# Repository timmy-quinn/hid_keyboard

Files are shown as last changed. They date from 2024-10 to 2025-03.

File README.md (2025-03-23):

# The KeyBird
The KeyBird is a BLE split keyboard with a vertical stagger and 5 thumb keys. It features hot-swap sockets compatible with any MX switches. The design is inspired by other popular split keyboards such as the [Corne](https://github.com/foostan/crkbd) or [Kinesis keyboards](https://kinesis-ergo.com/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).
  
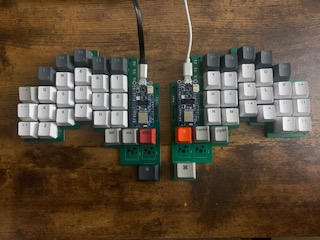
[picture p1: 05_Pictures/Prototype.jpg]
  

## Project Status
### Firmware 
- [x] Proof of concept: Single board BLE HID over GATT
- [x] Key matrix
- [x] Multi-role functionality
- [x] Process keypresses from secondary keyboard
- [ ] Improvements based on user experience
### Electronics 
- [x] Proof of concept: Perf board
- [x] Design and order PCBs
- [x] Assemble PCBs
- [ ] Improvements based on user experience 
### Case
- [x] Design case and plate
- [ ] 3D-print case and plate
- [ ] Build a wooden case
### Stretch goals
- [ ] Enable tenting
- [ ] Add NFC pairing capability
- [ ] Add USB option
- [ ] Add RGB LEDs
- [ ] OTA update
- [ ] Keyboard configuration via file upload

### Design Notes (AKA why does it look like that?) 
If you've never plunged down the ergonomic keyboard rabbit hole before, I'll give you a quick breakdown explaining some of the design decisions that went into my keyboard.  
  
**1. Split**  
Splitting a keyboard in half allows your hands and wrists to rest at a more natural and comfortable position  
**2. Ortholinear**   
This is just a fancy way to say that the keys are layed out in vertical columns, unlike typical keyboards, where the keys form horizontal rows, but are vertically staggered. Using vertical columns, especially when those columns are staggered to conform with the length of each finger, provides a more ergnomic typing experience.
**3. Reduced key count**  
Reducing the number of keys enables you to type faster and more efficiently since you do not have to stretch your fingers for hard to reach keys. This is especially helpful for coding, where you have to use symbols like ~ and | more often than most typers. But you might wonder, if you reduce the number of keys, don't you reduct the number of characters you can type? That is where the next design principle comes into play.
**4. Layers**  
A reduced keyboard makes up for its lack of keys by using layers. Layers are changed with the press of a button. When pressing the layer button, the same physical keys will transmit a different character to your PC. The shift key on a normal keyboard functions like this. On a reduced size keyboard, there will be at least one other layer key besides the shift key, enabling the same number of characters to be typed with fewer keys.  
**5. Thumb cluster**  
The thumb cluster solves one of the inefficiences of a standard keyboard, where both of your thumbs are dedicated to a single key. Adding a thumb cluster enables you to press far more keys without increasing how much you have to move your hand. This helps counter balance the reduced key size, while still preventing you from have to stretch and reach to use necessary keys.  
  
## Development requirements  
For hardware development KiCad 8 is used. 

For firmware Development nRF Connect SDK v2.6.1 is required. It can be conveniently used with the NRF Visual Studio Code Extension. More information can be found [here](https://docs.nordicsemi.com/bundle/ncs-latest/page/nrf/installation/install_ncs.html). 

#### Generating first build.  
1. Navigate to the NRF Connect Tab in VS Code.  
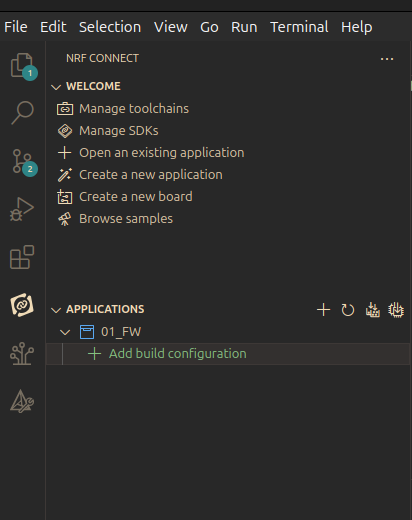
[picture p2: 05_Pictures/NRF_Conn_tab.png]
  
  
2. Select Add Build Configuration.  
  
  
3. Choose one of the presets. The presets are determined by the CMakePresets.json, but they can be simply be selected in the GUI.    
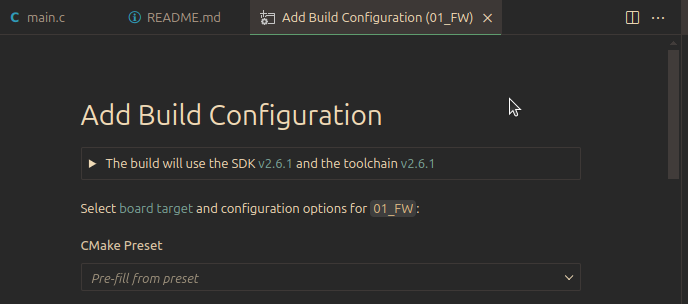
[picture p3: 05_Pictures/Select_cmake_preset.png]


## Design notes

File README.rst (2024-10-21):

.. _peripheral_hids_keyboard:

Bluetooth: Peripheral HIDS keyboard
###################################

.. contents::
   :local:
   :depth: 2

The Peripheral HIDS keyboard sample demonstrates how to use the :ref:`hids_readme` to implement a keyboard input device that you can connect to your computer.

The sample also shows how to perform LE Secure Connections Out-of-Band pairing using NFC.

Requirements
************

The sample supports the following development kits:

.. table-from-sample-yaml::

.. include:: /includes/tfm.txt

.. include:: /includes/hci_ipc_overlay.txt

If the NFC_OOB_PAIRING feature is enabled, the sample requires a smartphone or a tablet with Android v8.0.0 or newer.
- 

Overview
********

The sample uses the buttons on a development kit to simulate keys on a keyboard.
One button simulates the letter keys by generating letter keystrokes for a predefined string.
A second button simulates the Shift button and shows how to modify the letter keystrokes.
An LED displays the Caps Lock state, which can be modified by another connected keyboard.

This sample exposes the HID GATT Service.
It uses a report map for a generic keyboard.

LE Secure Out-of-Band pairing with NFC is enabled by default in this sample.
You can disable this feature by clearing the `NFC_OOB_PAIRING` flag in the application configuration.
The following paragraphs describe the application behavior when NFC pairing is enabled.

When the application starts, it initializes and starts the NFCT peripheral that is used for pairing.
The application does not start advertising immediately, but only when the NFC tag is read by an NFC polling device, for example a smartphone or a tablet with NFC support.
To trigger advertising without NFC, press **Button 4**.
The NDEF message that the tag sends to the NFC device contains data required to initiate pairing.
To start the NFC data transfer, the NFC device must touch the NFC antenna that is connected to the nRF52 device.

After reading the tag, the device can pair with the nRF52 device which is advertising.
After connecting, the sample application behaves in the same way as the original HID Keyboard sample.
Reading the NFC tag again when the application is in a connected state causes disconnection.
When the connection is lost, advertising does not restart automatically.

User interface
**************

Button 1:
   Sends one character of the predefined input ("hello\\n") to the computer.

   When pairing, press this button to confirm the passkey value that is printed on the COM listener to pair with the other device.

Button 2:
   Simulates the Shift key.

   When pairing, press this button to reject the passkey value which is printed on the COM listener to prevent pairing with the other device.

LED 1:
   Blinks with a period of two seconds with the duty cycle set to 50% when the main loop is running and the device is advertising.

LED 2:
   Lit when at least one device is connected.

LED 3:
   Indicates if Caps Lock is enabled.

If the `NFC_OOB_PAIRING` feature is enabled:

Button 4:
   Starts advertising.

LED 4:
   Indicates if an NFC field is present.

Configuration
*************

|config|

Setup
=====

The HID service specification does not require encryption (:kconfig:option:`CONFIG_BT_HIDS_DEFAULT_PERM_RW_ENCRYPT`), but some systems disconnect from the HID devices that do not support security.

Building and running
********************
.. |sample path| replace:: :file:`samples/bluetooth/peripheral_hids_keyboard`

.. include:: /includes/build_and_run_ns.txt

Testing
=======

After programming the sample to your development kit, you can test it either by connecting the kit as keyboard device to a Microsoft Windows computer or by connecting to it with `nRF Connect for Desktop`_.

Testing with a Microsoft Windows computer
-----------------------------------------

To test with a Microsoft Windows computer that has a Bluetooth® radio, complete the following steps:

1. Power on your development kit.
#. Press **Button 4** on the kit if the device is not advertising.
   A blinking **LED 1** indicates that the device is advertising.
#. |connect_terminal|
#. On your Windows computer, search for Bluetooth devices and connect to the device named "NCS HIDS keyboard".
#. Observe that the connection state is indicated by **LED 2**.
#. Open a text editor (for example, Notepad).
#. Repeatedly press **Button 1** on the kit.
   Every button press sends one character of the test message "hello" (the test message includes a carriage return) to the computer, and this will be displayed in the text editor.
#. Press **Button 2** and hold it while pressing **Button 1**.
   Observe that the next letter of the "hello" message appears as capital letter.
   This is because **Button 2** simulates the Shift key.
#. Turn on Caps Lock on the computer.
   Observe that **LED 3** turns on.
   This confirms that the output report characteristic has been written successfully on the HID device.
#. Turn Caps Lock off on the computer.
   Observe that **LED 3** turns off.
#. Disconnect the computer from the device by removing the device from the computer's devices list.

Testing with nRF Connect for Desktop
------------------------------------

To test with `nRF Connect for Desktop`_, complete the following steps:

1. Power on your development kit.
#. Press **Button 4** on the kit if the device is not advertising.
   A blinking **LED 1** indicates that the device is advertising.
#. |connect_terminal|
#. Start `nRF Connect for Desktop`_.
#. Open the Bluetooth Low Energy app.
#. Connect to the device from the app. The device is advertising as "NCS HIDS keyboard".
#. Pair the devices:

   a. Click the :guilabel:`Settings` button for the device in the app.
   #. Select :guilabel:`Pair`.
   #. Optionally, select :guilabel:`Perform Bonding`.

   Optionally, check :guilabel:`Enable MITM protection` to pair with MITM protection and use a button on the device to confirm or reject the passkey value.

   Wait until the bond is established before you continue.

#. Observe that the connection state is indicated by **LED 2**.
#. Observe that the services of the connected device are shown.
#. Enable notifications for all HID characteristics.
#. Press **Button 1** on the kit.
   Observe that two notifications are received on one of the HID Report characteristics, denoting press and release for one character of the test message.

   The first notification has the value ``00000B0000000000``, the second has the value ``0000000000000000``.
   The received values correspond to press and release of character "h".
   The format used for keyboard reports is the following byte array: ``[modifier, reserved, Key1, Key2, Key3, Key4, Key5, Key6]``.

   Similarly, further press and release events will result in press and release notifications of subsequent characters of the test string.
   Therefore, pressing **Button 1** again will result in notification of press and release reports for character "e".
#. Press **Button 2** and hold it while pressing **Button 1**.
   Pressing **Button 2** changes the modifier bit to 02, which simulates pressing the Shift key on a keyboard.

   Observe that two notifications are received on one of the HID Report characteristics, denoting press and release for one character of the test message.
   The first one has the value ``02000F0000000000``, the second has the value ``0200000000000000``.
   These values correspond to press and release of character "l" with the Shift key pressed.
#. In the Bluetooth Low Energy app, select the HID Report (which has UUID ``0x2A4D`` and the properties ``Read``, ``WriteWithoutResponse``, and ``Write``).
   Enter ``02`` in the text box and click the :guilabel:`tick mark` button.
   This sets the modifier bit of the Output Report to 02, which simulates turning Caps Lock ON.

   Observe that **LED 3** is lit.
#. Select the same HID Report again.
   Enter ``00`` in the text box and click :guilabel:`Write`.
   This sets the modifier bit to 00, which simulates turning Caps Lock OFF.

   Observe that **LED 3** turns off.
#. Disconnect the device in the Bluetooth Low Energy app.
   Observe that no new notifications are received.
#. If the advertising did not start automatically, press **Button 4** to continue advertising.
#. As bond information is preserved by the Bluetooth Low Energy app, you can immediately reconnect to the device by clicking the :guilabel:`Connect` button again.

Testing with Android using NFC for pairing
------------------------------------------

To test with an Android smartphone/tablet, complete the following steps:

1. Touch the NFC antenna with the smartphone or tablet and observe that **LED 4** is lit.
#. Observe that the device is advertising, as indicated by blinking **LED 1**.
#. Confirm pairing with 'Nordic_HIDS_keyboard' in a pop-up window on the smartphone/tablet.
#. Observe that the connection state is indicated by **LED 2**.
#. Repeatedly press **Button 1** on the kit.
   Every button press sends one character of the test message "hello" to the smartphone (the test message includes a carriage return).
#. Press **Button 2** and hold it while pressing **Button 1**.
   Observe that the next letter of the "hello" message appears as a capital letter.
   This is because **Button 2** simulates the Shift key.
#. Touch the NFC antenna with the same central device again.
#. Observe that devices disconnect.

Dependencies
************

This sample uses the following |NCS| libraries:

* :ref:`hids_readme`
* :ref:`nfc_ndef` (if the `NFC_OOB_PAIRING` option is enabled)
* :ref:`nfc_ndef_le_oob` (if the `NFC_OOB_PAIRING` option is enabled)

When the `NFC_OOB_PAIRING` feature is enabled, it also uses the Type 2 Tag library from `sdk-nrfxlib`_:

* :ref:`nrfxlib:nfc_api_type2`
* :ref:`dk_buttons_and_leds_readme`

The sample uses the following Zephyr libraries:

* :file:`include/zephyr/types.h`
* :file:`include/sys/printk.h`
* :file:`include/sys/byteorder.h`
* :ref:`GPIO Interface <zephyr:api_peripherals>`
* :ref:`zephyr:settings_api`
* :ref:`zephyr:bluetooth_api`:

  * :file:`include/bluetooth/bluetooth.h`
  * :file:`include/bluetooth/hci.h`
  * :file:`include/bluetooth/conn.h`
  * :file:`include/bluetooth/uuid.h`
  * :file:`include/bluetooth/gatt.h`
  * :file:`samples/bluetooth/gatt/bas.h`

References
**********

* `HID Service Specification`_
* `HID usage tables`_
* `Bluetooth Secure Simple Pairing Using NFC`_
* `Bluetooth Core Specification`_ Volume 3 Part H Chapter 2

The sample also uses the following secure firmware component:

* :ref:`Trusted Firmware-M <ug_tfm>`

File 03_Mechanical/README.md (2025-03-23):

#Keyboard Case and Plate Notes

[Jo scotto video gasket mount ](https://www.youtube.com/watch?v=W4mXZvFGHDg&t=625s)

- uses 4mm gaskets on both top and bottom  
- There is a 3.7 mm gap between the top of the plate and case, and bottom of plate and case,
despite the fact that a 4mm gasket is being used. This allows for the gasket to squish the
 board in place. 
- There is a gap between the side of the plate and the case of 0.25mm

[Jo Scotto case and plate](https://www.youtube.com/watch?v=7azQkSu0m_U)

[anatomy of a keyboard article](https://matt3o.com/anatomy-of-a-keyboard/) 

[cherry switches developer notes](https://www.cherry.de/en-gb/gaming/developer)

def test_layers(board):
    for drawing in board.GetDrawings():
        print("got drawing")
        print(f"Found drawing fo type:{type(drawing)} on layer ID: {drawing.GetLayer()}")
### Dimensions of a keyboard plate and case 
- From the top of the plate to the top of the PCBs is 5.0mm <br>
- The PCB and plate (when using an FR-4 plate will both be 1.6mm) <br>
    - For a 3d printed plate the plate should be thicker, 3mm to 5mm
    - At the top and bottom of a key switch are the clips. Below the clips are
    two little outcroppings that clip to the underside of the plate. To enable
     space for these little outcroppings, you need to make sure this part of the
      plate is 1.5mm thick. The area of these clips and outcroppings is 6mm long 
      and less than 1mm in width. To be safe we can add an extra mm or two for 
      tolerance. An area 7mm by 1-1.5mm should be adequate. 
- The thickness of the hot swappable socket is 1.85mm <br>
- The switch cutout holes should be 14mm by 14mm squares
<br>
#### Total distances from top of plate to bottom of case: <br>
10.45mm = 5 (top of plate to pcb) + 1.6 (pcb) + 1.85mm (hot swap socket) + 3mm (tolerance) <br>

#### Threaded inserts
For the threaded inserts that I am using, the material thickness is 3.2 mm and the length is 5.0mm

#### Integrated plate  
Raise the edged of the "case" 6mm above the "plate"

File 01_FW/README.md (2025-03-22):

# KeyBird Firmware

### Debug Tips

#### Unable to flash
```
[error] [ Client] - Encountered error -102: Command read_device_info executed for 125 milliseconds with result -102
[error] [ Worker] - An unknown error.
[error] [ Client] - Encountered error -102: Command read_memory_descriptors executed for 24 milliseconds with result -102
Failed to read device memories.
[error] [ Worker] - An unknown error.
ERROR: JLinkARM DLL reported an error. Try again. If error condition
ERROR: persists, run the same command again with argument --log, contact Nordic
ERROR: Semiconductor and provide the generated log.log file to them.
NOTE: For additional output, try running again with logging enabled (--log).
NOTE: Any generated log error messages will be displayed.
FATAL ERROR: command exited with status 33: nrfjprog --program /home/timmy/proj/hid_keyboard/01_FW/build_dbg_left/zephyr/zephyr.hex --sectoranduicrerase --verify -f NRF52 --snr 1050051174
```
The following error seems to occur occasionally. I'm not sure what causes it. 
The following solutions are recommended, but they've never worked for me. 
`nrfjprog --recover -f nrf52 --log` 
`nrfjprog --eraseall -f nrf52 --log` 

What worked for me was connecting to JLink directly. 
It seems that you may need to discuss the FTDI cable when doing this. 

```
JLinkExe
>> connect
```
Select 
- Device: nRF52840_xxAA
- Interface: SWD
- Speed: 4000

```
>> w4 4001e504 2 
>> w4 4001e400 1 
>> exit
```

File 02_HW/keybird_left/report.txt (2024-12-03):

Info: Processing symbol 'D24:Diode_SMD:Nexperia_CFP3_SOD-123W'.
Info: Processing symbol 'D29:Diode_SMD:Nexperia_CFP3_SOD-123W'.
Info: Processing symbol 'SW17:PCM_Switch_Keyboard_Cherry_MX:SW_Cherry_MX_PCB_1.25u'.
Info: Processing symbol 'D28:Diode_SMD:Nexperia_CFP3_SOD-123W'.
Info: Processing symbol 'D27:Diode_SMD:Nexperia_CFP3_SOD-123W'.
Info: Processing symbol 'SW18:PCM_Switch_Keyboard_Cherry_MX:SW_Cherry_MX_PCB_1.25u'.
Info: Processing symbol 'D26:Diode_SMD:Nexperia_CFP3_SOD-123W'.
Info: Processing symbol 'D25:Diode_SMD:Nexperia_CFP3_SOD-123W'.
Info: Processing symbol 'SW19:PCM_Switch_Keyboard_Cherry_MX:SW_Cherry_MX_PCB_1.25u'.
Info: Processing symbol 'D30:Diode_SMD:Nexperia_CFP3_SOD-123W'.
Info: Processing symbol 'D23:Diode_SMD:Nexperia_CFP3_SOD-123W'.
Info: Processing symbol 'SW20:PCM_Switch_Keyboard_Cherry_MX:SW_Cherry_MX_PCB_1.25u'.
Info: Processing symbol 'D22:Diode_SMD:Nexperia_CFP3_SOD-123W'.
Info: Processing symbol 'SW21:PCM_Switch_Keyboard_Cherry_MX:SW_Cherry_MX_PCB_1.25u'.
Info: Processing symbol 'D20:Diode_SMD:Nexperia_CFP3_SOD-123W'.
Info: Processing symbol 'D19:Diode_SMD:Nexperia_CFP3_SOD-123W'.
Info: Processing symbol 'SW22:PCM_Switch_Keyboard_Cherry_MX:SW_Cherry_MX_PCB_1.25u'.
Info: Processing symbol 'SW5:PCM_Switch_Keyboard_Cherry_MX:SW_Cherry_MX_PCB_1.25u'.
Info: Processing symbol 'SW11:PCM_Switch_Keyboard_Cherry_MX:SW_Cherry_MX_PCB_1.25u'.
Info: Processing symbol 'SW10:PCM_Switch_Keyboard_Cherry_MX:SW_Cherry_MX_PCB_1.25u'.
Info: Processing symbol 'SW9:PCM_Switch_Keyboard_Cherry_MX:SW_Cherry_MX_PCB_1.25u'.
Info: Processing symbol 'SW12:PCM_Switch_Keyboard_Cherry_MX:SW_Cherry_MX_PCB_1.25u'.
Info: Processing symbol 'SW8:PCM_Switch_Keyboard_Cherry_MX:SW_Cherry_MX_PCB_1.25u'.
Info: Processing symbol 'SW7:PCM_Switch_Keyboard_Cherry_MX:SW_Cherry_MX_PCB_1.25u'.
Info: Processing symbol 'SW13:PCM_Switch_Keyboard_Cherry_MX:SW_Cherry_MX_PCB_1.25u'.
Info: Processing symbol 'SW6:PCM_Switch_Keyboard_Cherry_MX:SW_Cherry_MX_PCB_1.25u'.
Info: Processing symbol 'D21:Diode_SMD:Nexperia_CFP3_SOD-123W'.
Info: Processing symbol 'SW14:PCM_Switch_Keyboard_Cherry_MX:SW_Cherry_MX_PCB_1.25u'.
Info: Processing symbol 'SW4:PCM_Switch_Keyboard_Cherry_MX:SW_Cherry_MX_PCB_1.25u'.
Info: Processing symbol 'SW3:PCM_Switch_Keyboard_Cherry_MX:SW_Cherry_MX_PCB_1.25u'.
Info: Processing symbol 'SW15:PCM_Switch_Keyboard_Cherry_MX:SW_Cherry_MX_PCB_1.25u'.
Info: Processing symbol 'SW2:PCM_Switch_Keyboard_Cherry_MX:SW_Cherry_MX_PCB_1.25u'.
Info: Processing symbol 'SW1:PCM_Switch_Keyboard_Cherry_MX:SW_Cherry_MX_PCB_1.25u'.
Info: Processing symbol 'SW16:PCM_Switch_Keyboard_Cherry_MX:SW_Cherry_MX_PCB_1.25u'.
Info: Processing symbol 'SW25:PCM_Switch_Keyboard_Cherry_MX:SW_Cherry_MX_PCB_1.25u'.
Info: Processing symbol 'SW28:PCM_Switch_Keyboard_Cherry_MX:SW_Cherry_MX_PCB_1.25u'.
Info: Processing symbol 'D7:Diode_SMD:Nexperia_CFP3_SOD-123W'.
Info: Processing symbol 'D6:Diode_SMD:Nexperia_CFP3_SOD-123W'.
Info: Processing symbol 'D8:Diode_SMD:Nexperia_CFP3_SOD-123W'.
Info: Processing symbol 'SW27:PCM_Switch_Keyboard_Cherry_MX:SW_Cherry_MX_PCB_1.25u'.
Info: Processing symbol 'D9:Diode_SMD:Nexperia_CFP3_SOD-123W'.
Info: Processing symbol 'D18:Diode_SMD:Nexperia_CFP3_SOD-123W'.
Info: Processing symbol 'D10:Diode_SMD:Nexperia_CFP3_SOD-123W'.
Info: Processing symbol 'SW26:PCM_Switch_Keyboard_Cherry_MX:SW_Cherry_MX_PCB_1.25u'.
Info: Processing symbol 'D11:Diode_SMD:Nexperia_CFP3_SOD-123W'.
Info: Processing symbol 'D5:Diode_SMD:Nexperia_CFP3_SOD-123W'.
Info: Processing symbol 'SW29:PCM_Switch_Keyboard_Cherry_MX:SW_Cherry_MX_PCB_1.25u'.
Info: Processing symbol 'D12:Diode_SMD:Nexperia_CFP3_SOD-123W'.
Info: Processing symbol 'D4:Diode_SMD:Nexperia_CFP3_SOD-123W'.
Info: Processing symbol 'SW30:PCM_Switch_Keyboard_Cherry_MX:SW_Cherry_MX_PCB_1.25u'.
Info: Processing symbol 'D1:Diode_SMD:Nexperia_CFP3_SOD-123W'.
Info: Processing symbol 'D17:Diode_SMD:Nexperia_CFP3_SOD-123W'.
Info: Processing symbol 'D2:Diode_SMD:Nexperia_CFP3_SOD-123W'.
Info: Processing symbol 'SW23:PCM_Switch_Keyboard_Cherry_MX:SW_Cherry_MX_PCB_1.25u'.
Info: Processing symbol 'D16:Diode_SMD:Nexperia_CFP3_SOD-123W'.
Info: Processing symbol 'D13:Diode_SMD:Nexperia_CFP3_SOD-123W'.
Info: Processing symbol 'D3:Diode_SMD:Nexperia_CFP3_SOD-123W'.
Info: Processing symbol 'D15:Diode_SMD:Nexperia_CFP3_SOD-123W'.
Info: Processing symbol 'SW24:PCM_Switch_Keyboard_Cherry_MX:SW_Cherry_MX_PCB_1.25u'.
Info: Processing symbol 'D14:Diode_SMD:Nexperia_CFP3_SOD-123W'.
Add SW13 (footprint 'PCM_Switch_Keyboard_Cherry_MX:SW_Cherry_MX_PCB_1.25u').
Add SW11 (footprint 'PCM_Switch_Keyboard_Cherry_MX:SW_Cherry_MX_PCB_1.25u').
Add SW28 (footprint 'PCM_Switch_Keyboard_Cherry_MX:SW_Cherry_MX_PCB_1.25u').
Add SW29 (footprint 'PCM_Switch_Keyboard_Cherry_MX:SW_Cherry_MX_PCB_1.25u').
Add SW12 (footprint 'PCM_Switch_Keyboard_Cherry_MX:SW_Cherry_MX_PCB_1.25u').
Add SW16 (footprint 'PCM_Switch_Keyboard_Cherry_MX:SW_Cherry_MX_PCB_1.25u').
Add SW14 (footprint 'PCM_Switch_Keyboard_Cherry_MX:SW_Cherry_MX_PCB_1.25u').
Add SW27 (footprint 'PCM_Switch_Keyboard_Cherry_MX:SW_Cherry_MX_PCB_1.25u').
Add SW15 (footprint 'PCM_Switch_Keyboard_Cherry_MX:SW_Cherry_MX_PCB_1.25u').
Add SW26 (footprint 'PCM_Switch_Keyboard_Cherry_MX:SW_Cherry_MX_PCB_1.25u').
Add SW17 (footprint 'PCM_Switch_Keyboard_Cherry_MX:SW_Cherry_MX_PCB_1.25u').
Add SW25 (footprint 'PCM_Switch_Keyboard_Cherry_MX:SW_Cherry_MX_PCB_1.25u').
Add SW18 (footprint 'PCM_Switch_Keyboard_Cherry_MX:SW_Cherry_MX_PCB_1.25u').
Add SW24 (footprint 'PCM_Switch_Keyboard_Cherry_MX:SW_Cherry_MX_PCB_1.25u').
Add SW19 (footprint 'PCM_Switch_Keyboard_Cherry_MX:SW_Cherry_MX_PCB_1.25u').
Add SW23 (footprint 'PCM_Switch_Keyboard_Cherry_MX:SW_Cherry_MX_PCB_1.25u').
Add SW20 (footprint 'PCM_Switch_Keyboard_Cherry_MX:SW_Cherry_MX_PCB_1.25u').
Add SW30 (footprint 'PCM_Switch_Keyboard_Cherry_MX:SW_Cherry_MX_PCB_1.25u').
Add SW21 (footprint 'PCM_Switch_Keyboard_Cherry_MX:SW_Cherry_MX_PCB_1.25u').
Add SW22 (footprint 'PCM_Switch_Keyboard_Cherry_MX:SW_Cherry_MX_PCB_1.25u').
Add D10 (footprint 'Diode_SMD:Nexperia_CFP3_SOD-123W').
Add D19 (footprint 'Diode_SMD:Nexperia_CFP3_SOD-123W').
Add D18 (footprint 'Diode_SMD:Nexperia_CFP3_SOD-123W').
Add D17 (footprint 'Diode_SMD:Nexperia_CFP3_SOD-123W').
Add D16 (footprint 'Diode_SMD:Nexperia_CFP3_SOD-123W').
Add D15 (footprint 'Diode_SMD:Nexperia_CFP3_SOD-123W').
Add D14 (footprint 'Diode_SMD:Nexperia_CFP3_SOD-123W').
Add D13 (footprint 'Diode_SMD:Nexperia_CFP3_SOD-123W').
Add D12 (footprint 'Diode_SMD:Nexperia_CFP3_SOD-123W').
Add D11 (footprint 'Diode_SMD:Nexperia_CFP3_SOD-123W').
Add D20 (footprint 'Diode_SMD:Nexperia_CFP3_SOD-123W').
Add D9 (footprint 'Diode_SMD:Nexperia_CFP3_SOD-123W').
Add D8 (footprint 'Diode_SMD:Nexperia_CFP3_SOD-123W').
Add D7 (footprint 'Diode_SMD:Nexperia_CFP3_SOD-123W').
Add D6 (footprint 'Diode_SMD:Nexperia_CFP3_SOD-123W').
Add D5 (footprint 'Diode_SMD:Nexperia_CFP3_SOD-123W').
Add D4 (footprint 'Diode_SMD:Nexperia_CFP3_SOD-123W').
Add D3 (footprint 'Diode_SMD:Nexperia_CFP3_SOD-123W').
Add D2 (footprint 'Diode_SMD:Nexperia_CFP3_SOD-123W').
Add D1 (footprint 'Diode_SMD:Nexperia_CFP3_SOD-123W').
Add D30 (footprint 'Diode_SMD:Nexperia_CFP3_SOD-123W').
Add SW9 (footprint 'PCM_Switch_Keyboard_Cherry_MX:SW_Cherry_MX_PCB_1.25u').
Add SW8 (footprint 'PCM_Switch_Keyboard_Cherry_MX:SW_Cherry_MX_PCB_1.25u').
Add SW7 (footprint 'PCM_Switch_Keyboard_Cherry_MX:SW_Cherry_MX_PCB_1.25u').
Add SW6 (footprint 'PCM_Switch_Keyboard_Cherry_MX:SW_Cherry_MX_PCB_1.25u').
Add SW5 (footprint 'PCM_Switch_Keyboard_Cherry_MX:SW_Cherry_MX_PCB_1.25u').
Add SW4 (footprint 'PCM_Switch_Keyboard_Cherry_MX:SW_Cherry_MX_PCB_1.25u').
Add SW3 (footprint 'PCM_Switch_Keyboard_Cherry_MX:SW_Cherry_MX_PCB_1.25u').
Add SW2 (footprint 'PCM_Switch_Keyboard_Cherry_MX:SW_Cherry_MX_PCB_1.25u').
Add SW1 (footprint 'PCM_Switch_Keyboard_Cherry_MX:SW_Cherry_MX_PCB_1.25u').
Add SW10 (footprint 'PCM_Switch_Keyboard_Cherry_MX:SW_Cherry_MX_PCB_1.25u').
Add D29 (footprint 'Diode_SMD:Nexperia_CFP3_SOD-123W').
Add D28 (footprint 'Diode_SMD:Nexperia_CFP3_SOD-123W').
Add D27 (footprint 'Diode_SMD:Nexperia_CFP3_SOD-123W').
Add D26 (footprint 'Diode_SMD:Nexperia_CFP3_SOD-123W').
Add D25 (footprint 'Diode_SMD:Nexperia_CFP3_SOD-123W').
Add D24 (footprint 'Diode_SMD:Nexperia_CFP3_SOD-123W').
Add D23 (footprint 'Diode_SMD:Nexperia_CFP3_SOD-123W').
Add D22 (footprint 'Diode_SMD:Nexperia_CFP3_SOD-123W').
Add D21 (footprint 'Diode_SMD:Nexperia_CFP3_SOD-123W').

Info: Total warnings: 0, errors: 0.

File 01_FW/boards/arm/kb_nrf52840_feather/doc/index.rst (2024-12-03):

.. _adafruit_feather_nrf52840:

Adafruit Feather nRF52840 Express
#################################

Overview
********
This custom boards takes the Adafruit Feather nRF52840 board but board.cmake is modified to enable flashing with nrfjprog runner.

The Adafruit Feather nRF52840 provides support for the Nordic Semiconductor
nRF52840 ARM Cortex-M4F CPU and the following devices:

* :abbr:`ADC (Analog to Digital Converter)`
* CLOCK
* FLASH
* :abbr:`GPIO (General Purpose Input Output)`
* :abbr:`I2C (Inter-Integrated Circuit)`
* :abbr:`MPU (Memory Protection Unit)`
* :abbr:`NVIC (Nested Vectored Interrupt Controller)`
* :abbr:`PWM (Pulse Width Modulation)`
* RADIO (Bluetooth Low Energy and 802.15.4)
* :abbr:`RTC (nRF RTC System Clock)`
* Segger RTT (RTT Console)
* :abbr:`SPI (Serial Peripheral Interface)`
* :abbr:`UART (Universal asynchronous receiver-transmitter)`
* :abbr:`USB (Universal Serial Bus)`
* :abbr:`WDT (Watchdog Timer)`

Adafruit Feather nRF52840 Express

Hardware
********

- nRF52840 ARM Cortex-M4F processor at 64 MHz
- 1 MB flash memory and 256 KB of SRAM
- Battery connector and charger for 3.7 V lithium polymer batteries
- Charging indicator LED
- 2 User LEDs
- 1 NeoPixel LED
- Reset button
- SWD connector

Supported Features
==================

The Adafruit Feather nRF52840 board configuration supports the
following hardware features:

+-----------+------------+----------------------+
| Interface | Controller | Driver/Component     |
+===========+============+======================+
| ADC       | on-chip    | adc                  |
+-----------+------------+----------------------+
| CLOCK     | on-chip    | clock_control        |
+-----------+------------+----------------------+
| FLASH     | on-chip    | flash                |
+-----------+------------+----------------------+
| GPIO      | on-chip    | gpio                 |
+-----------+------------+----------------------+
| I2C       | on-chip    | i2c                  |
+-----------+------------+----------------------+
| MPU       | on-chip    | arch/arm             |
+-----------+------------+----------------------+
| NVIC      | on-chip    | arch/arm             |
+-----------+------------+----------------------+
| PWM       | on-chip    | pwm                  |
+-----------+------------+----------------------+
| RADIO     | on-chip    | Bluetooth,           |
|           |            | ieee802154           |
+-----------+------------+----------------------+
| RTC       | on-chip    | system clock         |
+-----------+------------+----------------------+
| SPI       | on-chip    | spi                  |
+-----------+------------+----------------------+
| UART      | on-chip    | serial               |
+-----------+------------+----------------------+
| USB       | on-chip    | usb                  |
+-----------+------------+----------------------+
| WDT       | on-chip    | watchdog             |
+-----------+------------+----------------------+

Other hardware features have not been enabled yet for this board.

Connections and IOs
===================

The `Adafruit Feather nRF52840 Express Learn site`_ has detailed
information about the board including `pinouts`_ and the `schematic`_.

LED
---

* LED0 (red) = P1.15
* LED1 (blue) = P1.10

Push buttons
------------

* SWITCH = P1.02
* RESET = P0.18

Programming and Debugging
*************************

Applications for the ``adafruit_feather_nrf52840`` board configuration
can be built and flashed in the usual way (see :ref:`build_an_application`
and :ref:`application_run` for more details).

Flashing
========

Flashing Zephyr onto the ``adafruit_feather_nrf52480`` board requires
an external programmer. The programmer is attached to the SWD header.

Build the Zephyr kernel and the :zephyr:code-sample:`blinky` sample application.

   .. zephyr-app-commands::
      :zephyr-app: samples/basic/blinky
      :board: adafruit_feather_nrf52840
      :goals: build
      :compact:

Flash the image.

   .. zephyr-app-commands::
      :zephyr-app: samples/basic/blinky
      :board: adafruit_feather_nrf52840
      :goals: flash
      :compact:

You should see the red LED blink.

References
**********

.. target-notes::

.. _Adafruit Feather nRF52840 Express Learn site:
    https://learn.adafruit.com/introducing-the-adafruit-nrf52840-feather/

.. _pinouts:
    https://learn.adafruit.com/introducing-the-adafruit-nrf52840-feather/pinouts

.. _schematic:
    https://learn.adafruit.com/introducing-the-adafruit-nrf52840-feather/downloads

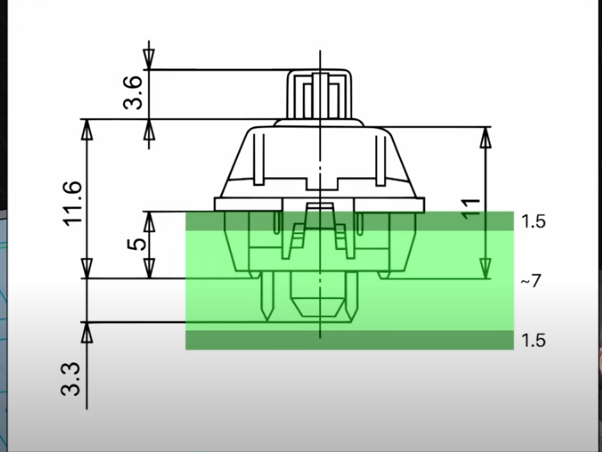
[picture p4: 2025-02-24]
03_Mechanical/photos/key_case_dimensions.png

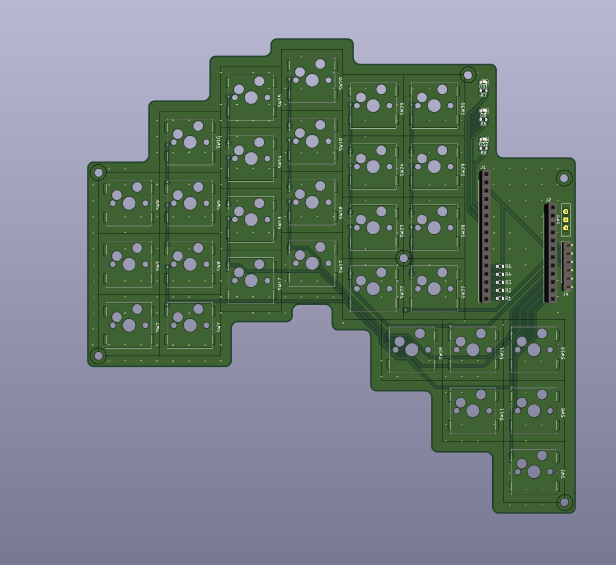
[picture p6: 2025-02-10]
05_Pictures/kb_left.png

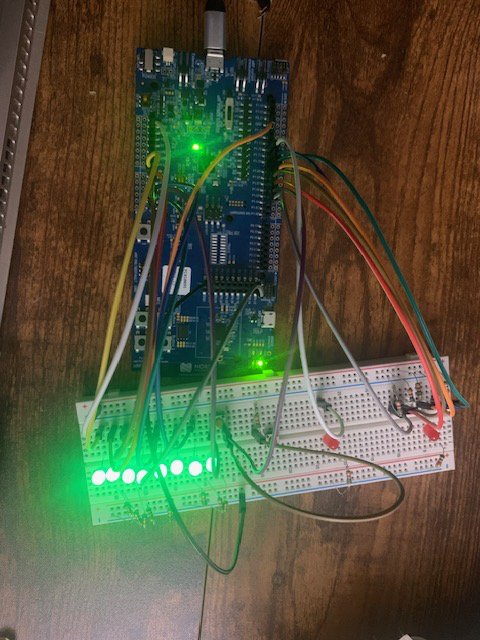
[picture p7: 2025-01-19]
05_Pictures/KeyBird_P1.jpg

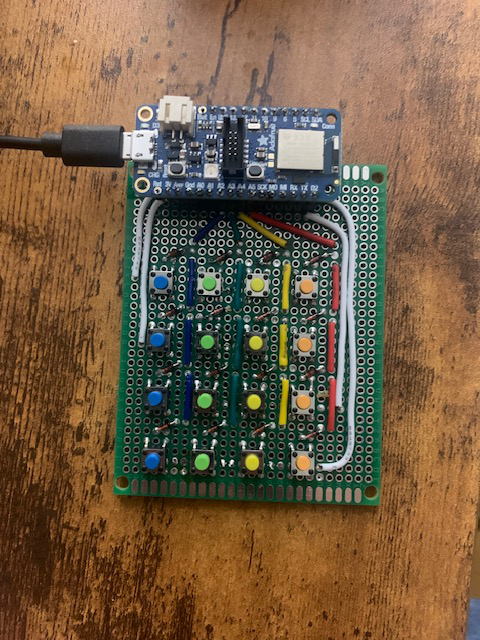
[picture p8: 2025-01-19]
05_Pictures/KeyBird_P2.jpg

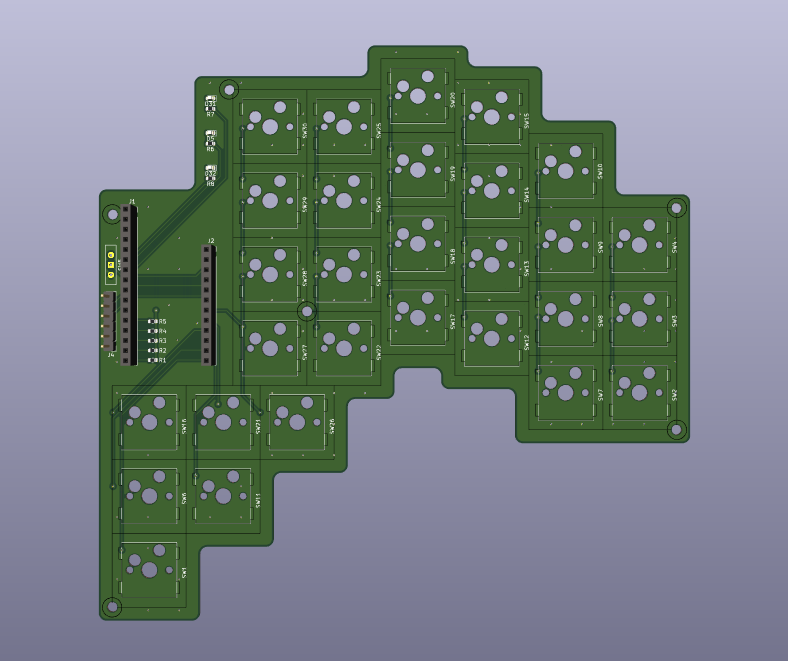
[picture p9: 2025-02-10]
05_Pictures/kb_right.png

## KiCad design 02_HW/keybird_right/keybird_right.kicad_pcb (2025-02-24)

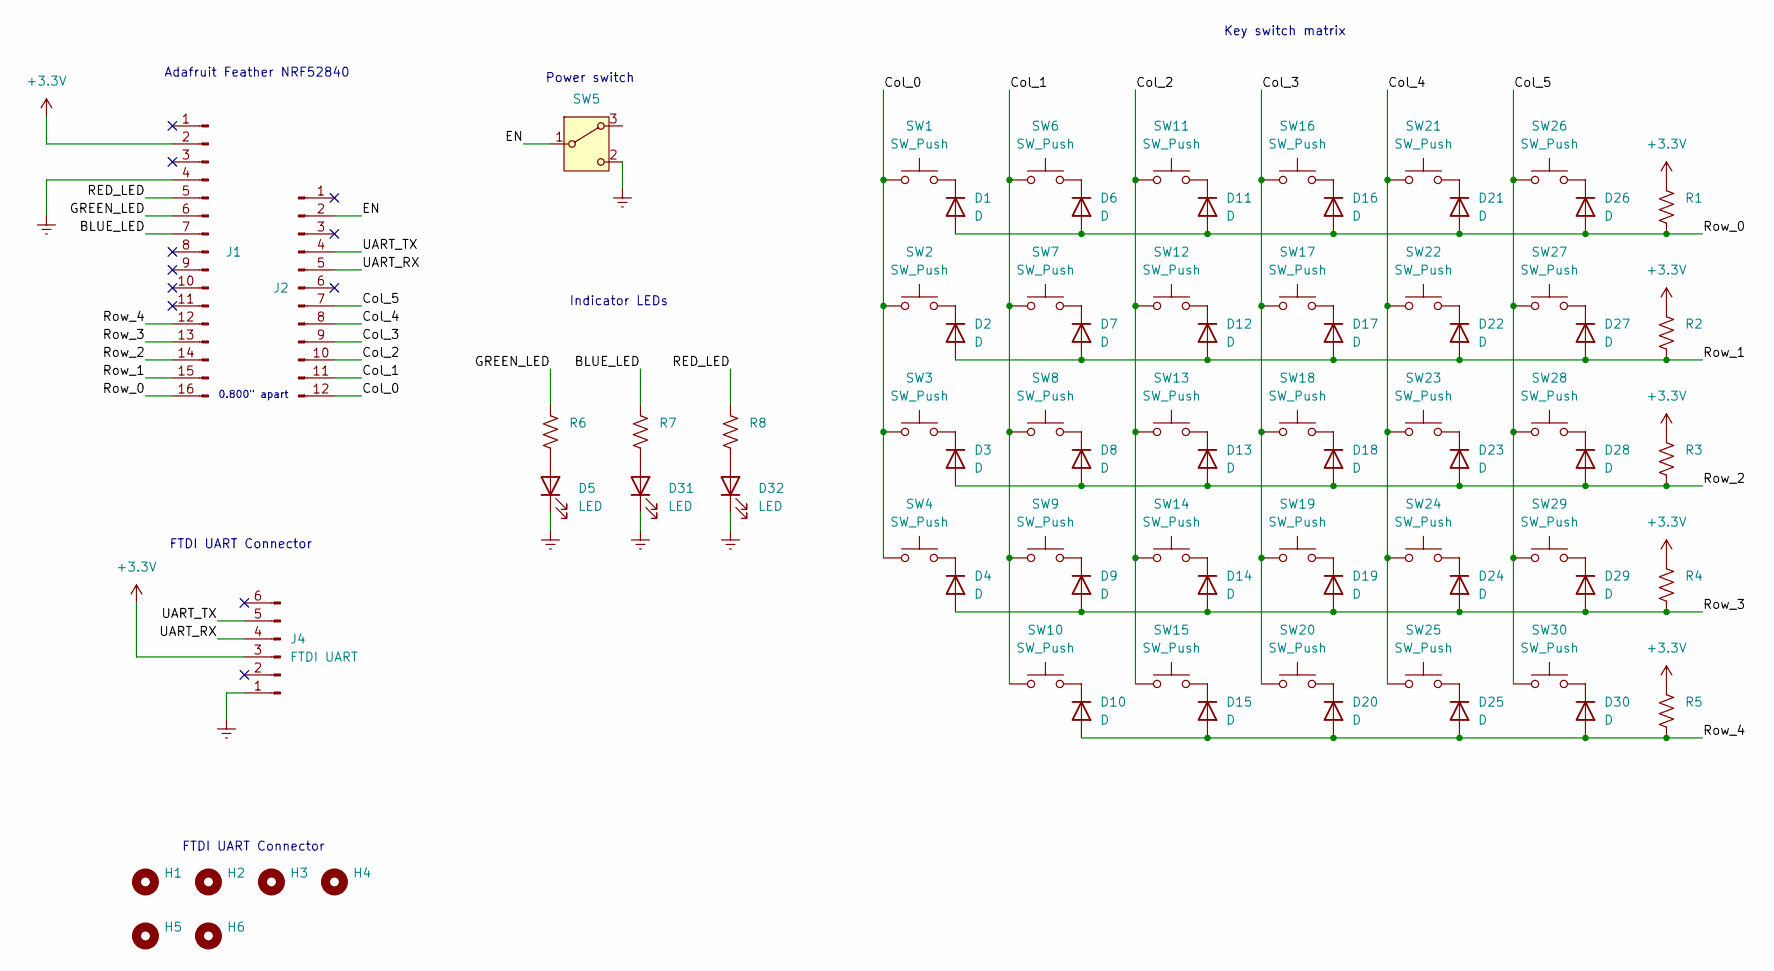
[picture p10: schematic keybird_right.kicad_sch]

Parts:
D1, D2, D3, D4, D6, D7, D8, D9, D10, D11, D12, D13, D14, D15, D16, D17, D18, D19, D20, D21, D22, D23, D24, D25, D26, D27, D28, D29, D30: D; Nexperia_CFP3_SOD-123W
D5, D31, D32: LED; LED_0603_1608Metric
H1, H2, H3, H4, H5, H6: MountingHole; MountingHole_2.5mm
J1: Adafruit_Feather_16_pin; PinSocket_1x16_P2.54mm_Vertical
J2: Adafruit_feather_12_pin; PinSocket_1x12_P2.54mm_Vertical
J4: FTDI UART; PinHeader_1x06_P2.54mm_Vertical
R1, R2, R3, R4, R5, R6, R7, R8: R_US; R_0603_1608Metric
SW1, SW2, SW3, SW4, SW6, SW7, SW8, SW9, SW10, SW11, SW12, SW13, SW14, SW15, SW16, SW17, SW18, SW19, SW20, SW21, SW22, SW23, SW24, SW25, SW26, SW27, SW28, SW29, SW30: SW_Push; SW_Hotswap_Kailh_MX_1.00u
SW5: Power enable; SW_Slide-03_Wuerth-WS-SLTV_10x2.5x6.4_P2.54mm

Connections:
+3.3V: J1.2, J4.3, R1.1, R2.1, R3.1, R4.1, R5.1
/BLUE_LED: J1.7, R7.1
/Col_0: J2.12, SW1.1, SW2.1, SW3.1, SW4.1
/Col_1: J2.11, SW6.1, SW7.1, SW8.1, SW9.1, SW10.1
/Col_2: J2.10, SW11.1, SW12.1, SW13.1, SW14.1, SW15.1
/Col_3: J2.9, SW16.1, SW17.1, SW18.1, SW19.1, SW20.1
/Col_4: J2.8, SW21.1, SW22.1, SW23.1, SW24.1, SW25.1
/Col_5: J2.7, SW26.1, SW27.1, SW28.1, SW29.1, SW30.1
/EN: J2.2, SW5.1 (B)
/GREEN_LED: J1.6, R6.1
/RED_LED: J1.5, R8.1
/Row_0: D1.2 (A), D6.2 (A), D11.2 (A), D16.2 (A), D21.2 (A), D26.2 (A), J1.16, R1.2
/Row_1: D2.2 (A), D7.2 (A), D12.2 (A), D17.2 (A), D22.2 (A), D27.2 (A), J1.15, R2.2
/Row_2: D3.2 (A), D8.2 (A), D13.2 (A), D18.2 (A), D23.2 (A), D28.2 (A), J1.14, R3.2
/Row_3: D4.2 (A), D9.2 (A), D14.2 (A), D19.2 (A), D24.2 (A), D29.2 (A), J1.13, R4.2
/Row_4: D10.2 (A), D15.2 (A), D20.2 (A), D25.2 (A), D30.2 (A), J1.12, R5.2
/UART_RX: J2.5, J4.4
/UART_TX: J2.4, J4.5
GNDREF: D5.1 (K), D31.1 (K), D32.1 (K), J1.4, J4.1, SW5.2 (C)
unnamed: D1.1 (K), SW1.2
unnamed: D2.1 (K), SW2.2
unnamed: D3.1 (K), SW3.2
unnamed: D4.1 (K), SW4.2
unnamed: D5.2 (A), R6.2
unnamed: D6.1 (K), SW6.2
unnamed: D7.1 (K), SW7.2
unnamed: D8.1 (K), SW8.2
unnamed: D9.1 (K), SW9.2
unnamed: D10.1 (K), SW10.2
unnamed: D11.1 (K), SW11.2
unnamed: D12.1 (K), SW12.2
unnamed: D13.1 (K), SW13.2
unnamed: D14.1 (K), SW14.2
unnamed: D15.1 (K), SW15.2
unnamed: D16.1 (K), SW16.2
unnamed: D17.1 (K), SW17.2
unnamed: D18.1 (K), SW18.2
unnamed: D19.1 (K), SW19.2
unnamed: D20.1 (K), SW20.2
unnamed: D21.1 (K), SW21.2
unnamed: D22.1 (K), SW22.2
unnamed: D23.1 (K), SW23.2
unnamed: D24.1 (K), SW24.2
unnamed: D25.1 (K), SW25.2
unnamed: D26.1 (K), SW26.2
unnamed: D27.1 (K), SW27.2
unnamed: D28.1 (K), SW28.2
unnamed: D29.1 (K), SW29.2
unnamed: D30.1 (K), SW30.2
unnamed: D31.2 (A), R7.2
unnamed: D32.2 (A), R8.2

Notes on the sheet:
FTDI UART Connector
0.800" apart
Power switch
Adafruit Feather NRF52840
Indicator LEDs
Key switch matrix

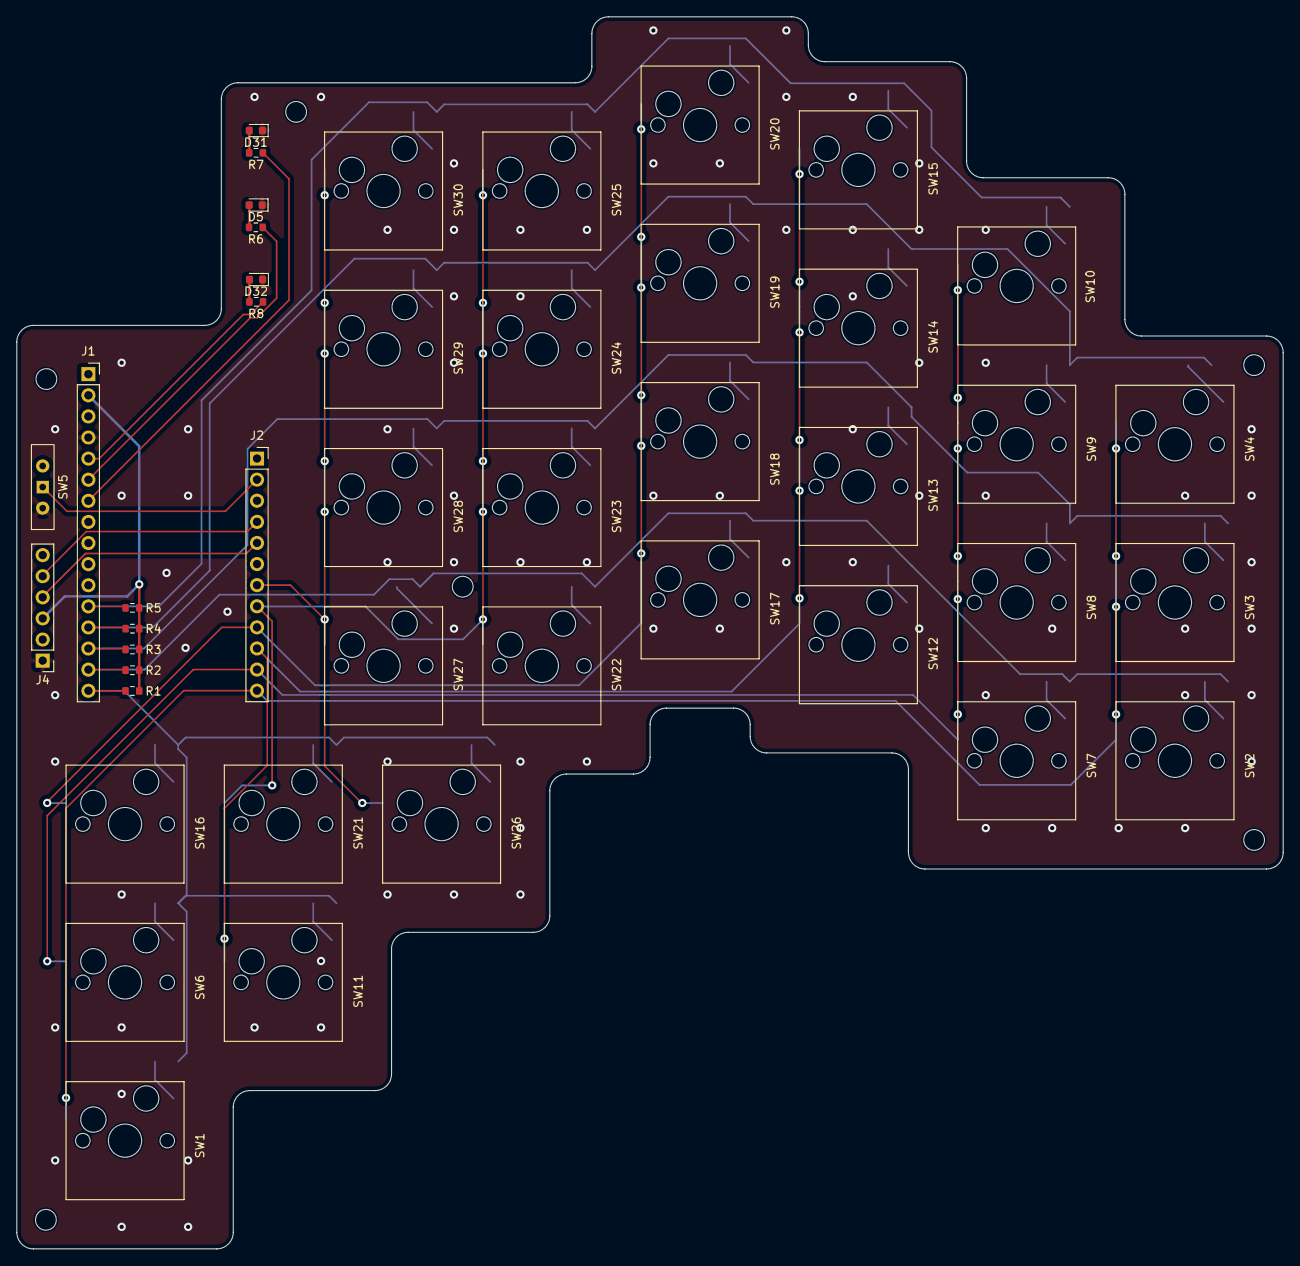
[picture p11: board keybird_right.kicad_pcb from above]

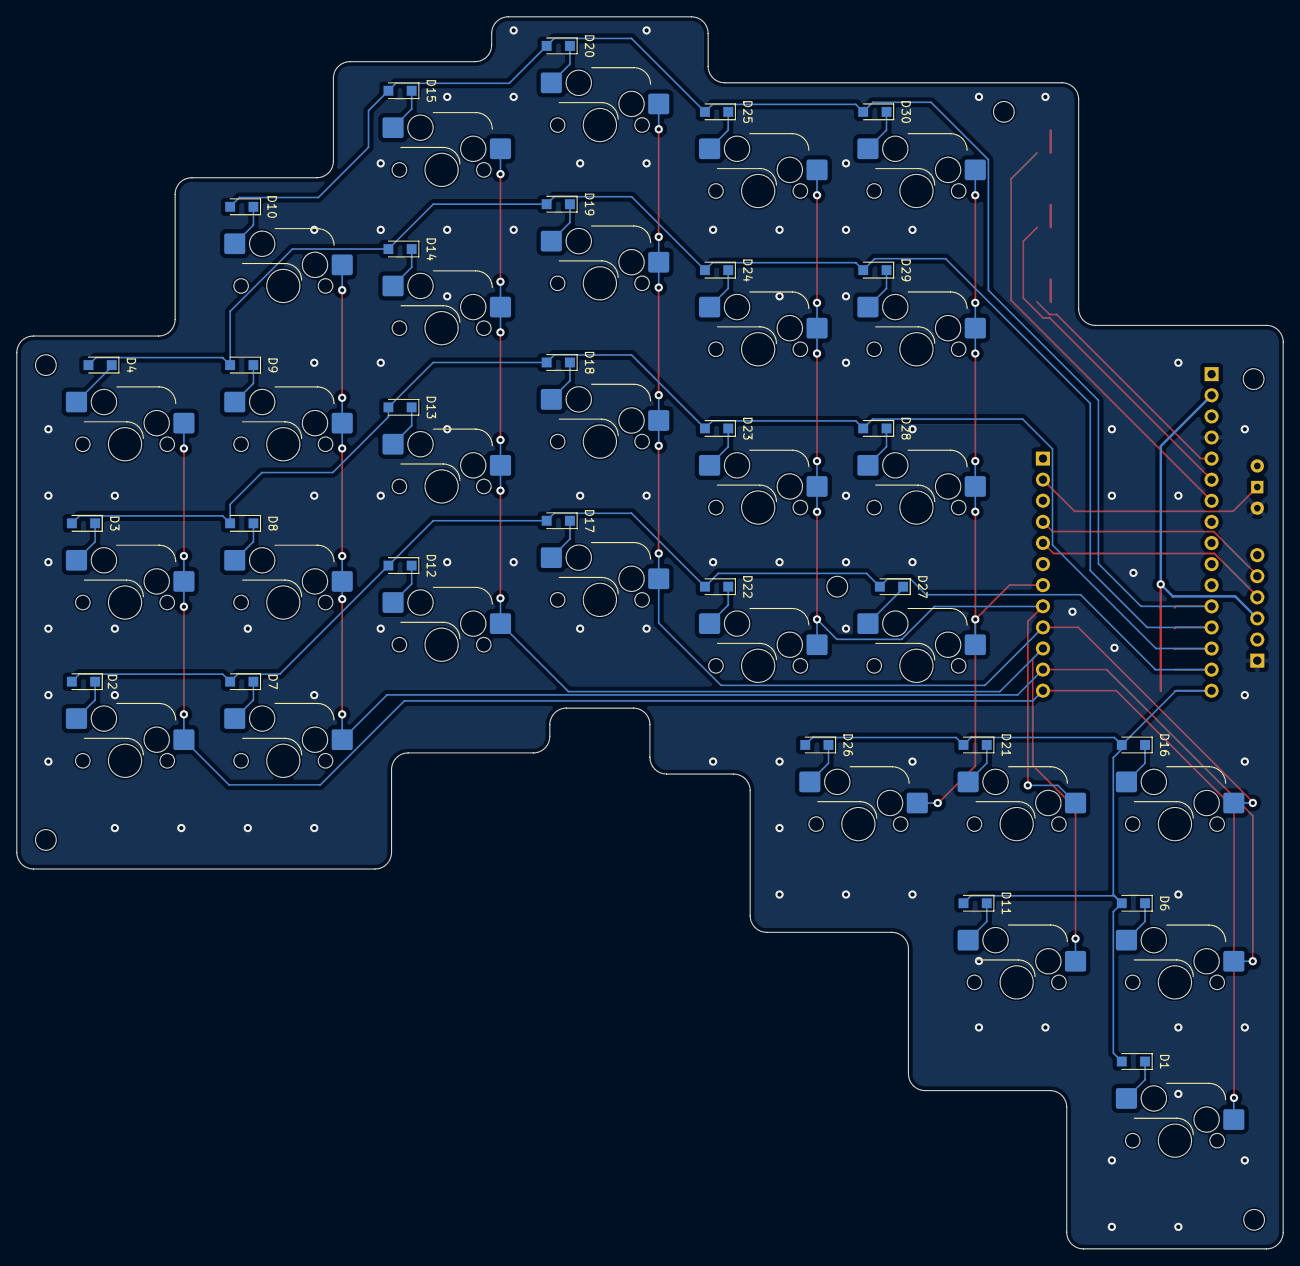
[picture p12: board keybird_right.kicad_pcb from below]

Board: 2 copper layers, 152.4 x 148.3 mm, 79 parts (35 on the bottom side), 51 nets.

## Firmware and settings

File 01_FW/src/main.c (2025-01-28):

#include <hal/nrf_gpio.h>
#include <zephyr/bluetooth/bluetooth.h>
#include <zephyr/drivers/gpio.h>
#include <zephyr/kernel.h>
#include <zephyr/settings/settings.h>

#include "btns.h"
#include "kb_ble/kb_ble.h"
#include "kb_ble/kb_cent.h"
#include "kb_ble/kb_periph.h"

#define ADV_LED_BLINK_INTERVAL 1000

static const struct gpio_dt_spec adv_status_led = GPIO_DT_SPEC_GET(DT_NODELABEL(led1), gpios);

int main(void) {
    int blink_status = 0;
    gpio_pin_configure_dt(&adv_status_led, GPIO_OUTPUT);

    // bt_enable must come before settings_load(); not 100% sure why, but bt_enable appears
    // to have a bt_settings_init usring similar macros
    if (ble_init()) {
        return 0;
    }

    if (IS_ENABLED(CONFIG_SETTINGS)) {
        printk("loading settings\n");
        settings_load();
    }
    kb_periph_init();
    printk("Intialized HID keyboard device\n");
    kb_cent_init();
    printk("Initialize HOGP\n");

    printk("Bluetooth initialized\n");
    btns_init();

    for (;;) {
        if (kb_periph_is_adv()) {
            gpio_pin_set_dt(&adv_status_led, (++blink_status) % 2);
        } else {
            gpio_pin_set_dt(&adv_status_led, 0);
        }
        k_sleep(K_MSEC(ADV_LED_BLINK_INTERVAL));
        /* Battery level simulation */
        kb_periph_bas_notify();
    }
}

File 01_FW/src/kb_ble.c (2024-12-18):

#include <zephyr/types.h>
#include <stddef.h>
#include <string.h>
#include <errno.h>
#include <zephyr/sys/printk.h>
#include <zephyr/sys/byteorder.h>
#include <zephyr/kernel.h>
#include <zephyr/drivers/gpio.h>
#include <soc.h>
#include <assert.h>
#include <zephyr/spinlock.h>

#include <zephyr/settings/settings.h>

#include <zephyr/bluetooth/bluetooth.h>
#include <zephyr/bluetooth/hci.h>
#include <zephyr/bluetooth/conn.h>
#include <zephyr/bluetooth/uuid.h>
#include <zephyr/bluetooth/gatt.h>

#include <zephyr/bluetooth/services/bas.h>
#include <bluetooth/services/hids.h>
#include <zephyr/bluetooth/services/dis.h>
#include <dk_buttons_and_leds.h>

#include "kb_ble.h"

#define DEVICE_NAME     CONFIG_BT_DEVICE_NAME
#define DEVICE_NAME_LEN (sizeof(DEVICE_NAME) - 1)

#define BASE_USB_HID_SPEC_VERSION   0x0101

#define OUTPUT_REPORT_MAX_LEN            1
#define OUTPUT_REPORT_BIT_MASK_CAPS_LOCK 0x02
#define INPUT_REP_KEYS_REF_ID            0
#define OUTPUT_REP_KEYS_REF_ID           0
#define MODIFIER_KEY_POS                 0
#define SHIFT_KEY_CODE                   0x02
#define SCAN_CODE_POS                    2
#define KEYS_MAX_LEN                    (INPUT_REPORT_KEYS_MAX_LEN - \
					SCAN_CODE_POS)

#define ADV_LED_BLINK_INTERVAL  1000

#define CON_STATUS_LED DK_LED2
#define LED_CAPS_LOCK  DK_LED3
#define NFC_LED	       DK_LED4
#define KEY_TEXT_MASK  DK_BTN1_MSK
#define KEY_SHIFT_MASK DK_BTN2_MSK
#define KEY_ADV_MASK   DK_BTN4_MSK

/* Key used to accept or reject passkey value */
#define KEY_PAIRING_ACCEPT DK_BTN1_MSK
#define KEY_PAIRING_REJECT DK_BTN2_MSK

/* HIDs queue elements. */
#define HIDS_QUEUE_SIZE 10

/* ********************* */
/* Buttons configuration */

/* Note: The configuration below is the same as BOOT mode configuration
 * This simplifies the code as the BOOT mode is the same as REPORT mode.
 * Changing this configuration would require separate implementation of
 * BOOT mode report generation.
 */
#define KEY_CTRL_CODE_MIN 224 /* Control key codes - required 8 of them */
#define KEY_CTRL_CODE_MAX 231 /* Control key codes - required 8 of them */
#define KEY_CODE_MIN      0   /* Normal key codes */
#define KEY_CODE_MAX      101 /* Normal key codes */
#define KEY_PRESS_MAX     6   /* Maximum number of non-control keys
			       * pressed simultaneously
			       */

/* Number of bytes in key report
 *
 * 1B - control keys
 * 1B - reserved
 * rest - non-control keys
 */
#define INPUT_REPORT_KEYS_MAX_LEN (1 + 1 + KEY_PRESS_MAX)

/* Current report map construction requires exactly 8 buttons */
BUILD_ASSERT((KEY_CTRL_CODE_MAX - KEY_CTRL_CODE_MIN) + 1 == 8);

/* OUT report internal indexes.
 *
 * This is a position in internal report table and is not related to
 * report ID.
 */
enum {
	OUTPUT_REP_KEYS_IDX = 0
};

/* INPUT report internal indexes.
 *
 * This is a position in internal report table and is not related to
 * report ID.
 */
enum {
	INPUT_REP_KEYS_IDX = 0
};

/* HIDS instance. */
BT_HIDS_DEF(hids_obj,
	    OUTPUT_REPORT_MAX_LEN,
	    INPUT_REPORT_KEYS_MAX_LEN);

static volatile bool is_adv;

static const struct bt_data ad[] = {
	BT_DATA_BYTES(BT_DATA_GAP_APPEARANCE,
		      (CONFIG_BT_DEVICE_APPEARANCE >> 0) & 0xff,
		      (CONFIG_BT_DEVICE_APPEARANCE >> 8) & 0xff),
	BT_DATA_BYTES(BT_DATA_FLAGS, (BT_LE_AD_GENERAL | BT_LE_AD_NO_BREDR)),
	BT_DATA_BYTES(BT_DATA_UUID16_ALL, BT_UUID_16_ENCODE(BT_UUID_HIDS_VAL),
					  BT_UUID_16_ENCODE(BT_UUID_BAS_VAL)),
};

static const struct bt_data sd[] = {
	BT_DATA(BT_DATA_NAME_COMPLETE, DEVICE_NAME, DEVICE_NAME_LEN),
};

static struct conn_mode {
	struct bt_conn *conn;
	bool in_boot_mode;
} conn_mode[CONFIG_BT_HIDS_MAX_CLIENT_COUNT];

static const uint8_t hello_world_str[] = {
	0x0b,	/* Key h */
	0x08,	/* Key e */
	0x0f,	/* Key l */
	0x0f,	/* Key l */
	0x12,	/* Key o */
	0x1E,   /* Key 1/! */	
	0x28,	/* Key Return */
};

static const uint8_t shift_key[] = { 225 };

/* Current report status
 */
static struct keyboard_state {
	uint8_t ctrl_keys_state; /* Current keys state */
	uint8_t keys_state[KEY_PRESS_MAX];
} hid_keyboard_state;


static struct k_work pairing_work;
struct pairing_data_mitm {
	struct bt_conn *conn;
	unsigned int passkey;
};

K_MSGQ_DEFINE(mitm_queue,
	      sizeof(struct pairing_data_mitm),
	      CONFIG_BT_HIDS_MAX_CLIENT_COUNT,
	      4);

static void advertising_start(void)
{
	int err;
	struct bt_le_adv_param *adv_param = BT_LE_ADV_PARAM(
						BT_LE_ADV_OPT_CONNECTABLE |
						BT_LE_ADV_OPT_ONE_TIME, // test this: will not start advertising after disconnect. 
						BT_GAP_ADV_FAST_INT_MIN_2, // 160*0.625ms=100ms minimal interval for fast advertising
						BT_GAP_ADV_FAST_INT_MAX_2, // maximum interval for fast adertising
						NULL);

	err = bt_le_adv_start(adv_param, ad, ARRAY_SIZE(ad), sd,
			      ARRAY_SIZE(sd));
	if (err) {
		if (err == -EALREADY) {
			printk("Advertising continued\n");
		} else {
			printk("Advertising failed to start (err %d)\n", err);
		}

		return;
	}

	is_adv = true;
	printk("Advertising successfully started\n");
}


static void pairing_process(struct k_work *work)
{
	int err;
	struct pairing_data_mitm pairing_data;

	char addr[BT_ADDR_LE_STR_LEN];

	err = k_msgq_peek(&mitm_queue, &pairing_data);
	if (err) {
		return;
	}

	bt_addr_le_to_str(bt_conn_get_dst(pairing_data.conn),
			  addr, sizeof(addr));

	printk("Passkey for %s: %06u\n", addr, pairing_data.passkey);
	printk("Press Button 1 to confirm, Button 2 to reject.\n");
}


static void connected(struct bt_conn *conn, uint8_t err)
{
	char addr[BT_ADDR_LE_STR_LEN];

	bt_addr_le_to_str(bt_conn_get_dst(conn), addr, sizeof(addr));

	if (err) {
		printk("Failed to connect to %s (%u)\n", addr, err);
		return;
	}

	printk("Connected %s\n", addr);
	dk_set_led_on(CON_STATUS_LED);

	err = bt_hids_connected(&hids_obj, conn);

	if (err) {
		printk("Failed to notify HID service about connection\n");
		return;
	}

	for (size_t i = 0; i < CONFIG_BT_HIDS_MAX_CLIENT_COUNT; i++) {
		if (!conn_mode[i].conn) {
			conn_mode[i].conn = conn;
			conn_mode[i].in_boot_mode = false;
			break;
		}
	}

	is_adv = false;
}


static void disconnected(struct bt_conn *conn, uint8_t reason)
{
	int err;
	bool is_any_dev_connected = false;
	char addr[BT_ADDR_LE_STR_LEN];

	bt_addr_le_to_str(bt_conn_get_dst(conn), addr, sizeof(addr));

	printk("Disconnected from %s (reason %u)\n", addr, reason);

	err = bt_hids_disconnected(&hids_obj, conn);

	if (err) {
		printk("Failed to notify HID service about disconnection\n");
	}

	for (size_t i = 0; i < CONFIG_BT_HIDS_MAX_CLIENT_COUNT; i++) {
		if (conn_mode[i].conn == conn) {
			conn_mode[i].conn = NULL;
		} else {
			if (conn_mode[i].conn) {
				is_any_dev_connected = true;
			}
		}
	}

	if (!is_any_dev_connected) {
		dk_set_led_off(CON_STATUS_LED);
	}

	advertising_start();
}
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

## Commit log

2024-11-10 implemented blink led test with device tree overlay
2024-11-15 bugfix - key scan functions, and all output pins set to high at the start
    [main.c]
2024-11-24 Added PCB design files
    [skeleton.kicad_pcb, skeleton.kicad_sch]
2024-11-24 Added footprints
    [skeleton.kicad_sch]
2024-11-26 Added header pins and diodes. Updated PCB from schematic
    [skeleton.kicad_pcb, skeleton.kicad_sch]
2024-11-27 Organized key layout
    [skeleton.kicad_pcb, skeleton.kicad_sch]
2024-11-29 Added adafruit board and board overlay
2024-12-01 Positioned key switches and diodes
    [skeleton.kicad_pcb]
2024-12-02 Positioned key switch columns. Began fixing net labels
    [skeleton.kicad_pcb, skeleton.kicad_sch]
2024-12-03 moved thumb pad, fixed net labels,added design rules
    [skeleton.kicad_sch]
2024-12-03 Updated thumb pad layout, rearranged silkscreen
    [skeleton.kicad_pcb]
2024-12-05 Added key matrix device tree key binding and added to kb dts
    [kb_keys.c, main.c]
2024-12-09 Updated board files to match prototype hardware
2024-12-12 Updated overlay to work with prototype board
2024-12-12 Changed name to KeyBird
    [keybird.kicad_pcb, keybird.kicad_sch]
2024-12-18 Implemented keyboard functionality for prototype board and printk funcitonality
2025-01-14 Functions as relay. Cleaning up code
2025-01-17 Added queue to kb_central for passing information to keypress get thread
2025-01-19 Added photos of prototypes to README.md
2025-01-25 Implements functional BLE relay
2025-01-27 bugfix: multi-key rollover with BLE relay
    [btns.c, kb_hid_common.h, main.c]
2025-01-28 bugfix: special buttons not working
    [btns.c]
2025-01-29 Reverseddiodes for active low implementation
    [keybird.kicad_pcb, keybird.kicad_sch]
2025-01-31 Added power switch and leds to pcb
2025-01-31 Updated uart connector to match ftdi cable pinout
    [keybird.kicad_pcb, keybird.kicad_sch]
2025-02-01 Added board outline
    [keybird.kicad_pcb]
2025-02-05 Trimmed down board shape, completed tracing, adding ground pours and via stitching
    [keybird.kicad_pcb, keybird.kicad_sch, skeleton.kicad_pcb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]
2025-02-05 moved through holes in schematics
2025-02-08 Resolved design rule conflicts
    [keybird.kicad_pcb, keybird.kicad_sch]
2025-02-09 Finalizes left hand keyboard and creates template for right hand keyboard
    [keybird.kicad_pcb, keybird_left.kicad_pcb, keybird_left.kicad_sch]
2025-02-09 Renames right keyboard project file
    [keybird_left.kicad_pcb, keybird_right.kicad_pcb, keybird_right.kicad_sch]
2025-02-09 left and right board pass design rule checks
    [keybird_left.kicad_pcb, keybird_right.kicad_pcb]
2025-02-09 Left and right boards pass design rule checks
    [keybird_left.kicad_pcb, keybird_left.kicad_sch, keybird_right.kicad_pcb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]
2025-02-09 Created output files
    [keybird_left-B_Cu.gbl, keybird_left-B_Mask.gbs, keybird_left-B_Paste.gbp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]
2025-02-09 Zip output files
    [keybird_left-B_Cu.gbl, keybird_left-B_Mask.gbs, keybird_left-B_Paste.gbp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]
2025-02-09 Added screenshots of pcb files
2025-02-10 Added folder for mechanical parts (keyboard case)
2025-02-17 Added notes on keyboard case design
2025-02-17 Edited hardware files
    [keybird_right.kicad_pcb]
2025-02-25 Ignore backup folders in kicad
2025-02-27 script can copy lines from footprints and paste them onto a new layer, however the positioning is off.
2025-03-03 Added note about switch cutout size
    [KeyBird.FCStd]
2025-03-09 added mechanical README
    [keybird_left-Edge_Cuts.dxf, keybird_left-User_Drawings.dxf, keybird_left-User_Eco1.dxf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]
2025-03-09 Moved button matrix configuration to overlay file
2025-03-22 Deleted unneeded files
    [KeyBird.FCStd, temp_proj-B_Cu.dxf, temp_proj-Edge_Cuts.dxf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]
2025-03-22 Removed unnecessary files
    [temp_proj.kicad_pcb]
2025-03-23 Removes unneeded files
    [keybird_left-Edge_Cuts.dxf, keybird_left-User_Drawings.dxf, keybird_left-User_Eco1.dxf]
